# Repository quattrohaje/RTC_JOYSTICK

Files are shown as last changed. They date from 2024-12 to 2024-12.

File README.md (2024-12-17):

# RTC_JOYSTICK
There was one free ISA8bit slot left in my IBM5160, so I decided to build an RTC card. I also wanted to try drawing in the new one
the Kicad program and try exporting and ordering from the DPS manufacturer.

The whole project consists of two parts RTC and gamert. Why like this? Originally, I only wanted RTC, but I was afraid that the card wouldn't hold well in the ISA slot
so i added the gameport which is bolted to the milled blank.
As I already wrote, it can be divided into two parts
- "RTC" consists of components U1,U2,Y1,BT1,JP1,J1,R1,R2,R3
- "Gameport" then from U3,U4,U5,U7,C2,C3,C4,C5,C6,C7,C8,C9,C10,C11,R4,R5,R6,R7,RN1 and RN2
- "Common" Capacitor C1 is common to both connections and should always be fitted.
Component values are not critical
- 10k resistors are classic metallic
- the 10n capacitors are ceramic
- the 51p capacitors are ceramic, it is not important to observe the exact value here, they can be 30-100p with a large tolerance (but probably all the same)
- RN1 8x1k0 8xresistor with common one input, RN2 4x10k 4x resistor with common one input. For RN2 it is good to stick to the 10k value

JP1 is used to clear the RTC clock in the DS12885 circuit
J1 is used to set the address to which the RTC circuit will communicate. I recommend 0x240 i.e. A1 shorted using a jumper

The installation is not complicated, there is no trickery.

I compiled the programs for GAL using Wincurl

The driver for controlling the RTC circuit is written in ASM and translated using NASM. Driver usage is in config.sys
device=c:\ibm\dsclock.sys 0x240
The driver is not completely finished yet, there were some errors in the original, I corrected them, but I still have to fine-tune it. The driver works with both RTC and gameport

A few photos from the project
rtc1
rtc2
rtc4
rtc5
rtc6
rtc7

https://github.com/user-attachments/assets/15338810-2ce5-4af2-8db0-e2d07ca02ab5

The inspiration was in these projects on github
https://github.com/spark2k06/RTC8088
https://github.com/roybaer/game_control_adapter

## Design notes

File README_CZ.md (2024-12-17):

# RTC_JOYSTICK
RTC a Joystick interface pro ISA 8bit XT/AT PC

V mém IBM5160 zbyl ještě jeden volný ISA8bit slot a tak jsem se rozhodl, že si postavím kartu RTC. Chtěl jsem si také vyzkoušet kreslit v novém
programu Kicad a  vyzkoušet export a objednání u výrobce DPS.

Celý projekt se skládá ze dvou částí RTC a gamertu. Proč takto ? Původně jsem chtěl jen RTC, ale bál jsem se , že by karta špatně držela v ISA slotu
a tak jsem přidal gameport, který je přišroubován k frézované záslepce.
Jak jsem již psal, dá se to rozdělit na dvě části 
- "RTC" se skládá ze součástek U1,U2,Y1,BT1,JP1,J1,R1,R2,R3
- "Gameport" pak z U3,U4,U5,U7,C2,C3,C4,C5,C6,C7,C8,C9,C10,C11,R4,R5,R6,R7,RN1 a RN2
- "Společné" Kondenzátor C1 je společný pro obě zapojení a měl by být vždy osazen.
Hodnoty součástek nejsou kritické 
- odpory 10k jsou klasické metalické
- kondenzátory 10n jsou keramické
- kondenzátory 51p jsou keramické, zde není důležité dodržet přesnou hodnotu můžou být s velkou tolerancí 30-100p (ale asi všechny stejně)
- RN1 8x1k0 8xrezistor se společným jedním vstupem, RN2 4x10k 4x rezistor se společným jedním vstupem . U RN2 je dobré dodržet 10k hodnotu

JP1 slouží k výmazu RTC hodin v obvodu DS12885
J1 slouží k nastavení adresy na které bude komunikovat RTC obvod. Doporučuji 0x240 tj. A1 zkratovaný pomocí jumperu

Osazení není složité, není tam žádná záludnost.

Programy pro GAL jsem kompiloval pomocí Wincurl

Driver pro ovládání RTC obvodu je psán v ASM a přeložen pomocí NASM. Použití driveru je v config.sys
device=c:\ibm\dsclock.sys 0x240
Driver ještě není úplně hotov, v originál byly nějaké chyby, ty jsem upravil, ale ještě to musím doladit. Driver funguje jak s RTC tak gameportem 

Pár fotek z projektu
rtc1
rtc2
rtc4
rtc5
rtc6
rtc7

https://github.com/user-attachments/assets/15338810-2ce5-4af2-8db0-e2d07ca02ab5

Inspirace byla v těchto projektech na github
https://github.com/spark2k06/RTC8088
https://github.com/roybaer/game_control_adapter

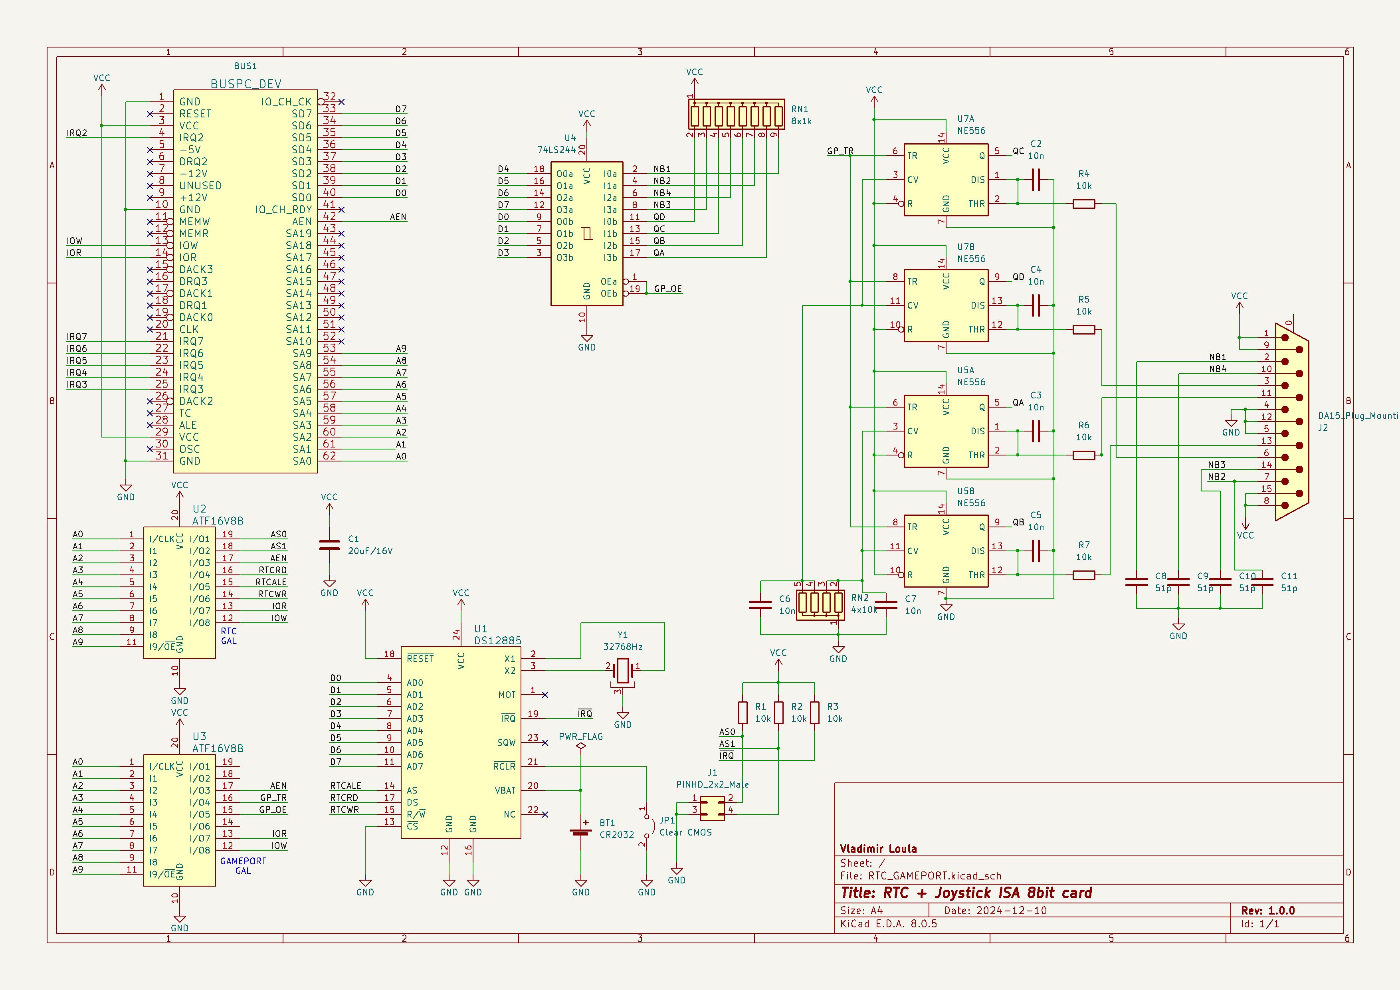
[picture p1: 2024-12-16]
Schematic.jpg

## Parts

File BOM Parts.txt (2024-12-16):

U1	DS12885		DIL24
U2	GAL16V8		DIL20
U3	GAL16V8		DIL20
U4	74LS244		DIL20
U5	NE556		DIL14
U7	NE556		DIL14
Y1	32768Hz
C1	20uF/16V
C2	10n
C3	10n
C4	10n
C5	10n
C6	10n
C7	10n
C8	50p
C9	50p
C10	50p
C11	50p
R1	10k
R2	10k
R3	10k
R4	10k
R5	10k
R6	10k
R7	10k
RN1	8x1k0
RN2	4x10k
J1 	2x2 pinhead
JP1	1x2 pinhead
J2	DSUB15 female 90° PCB
JMP1	jumper
JMP2	jumper
JMP3	jumper
BT1   držák na baterii CR2032

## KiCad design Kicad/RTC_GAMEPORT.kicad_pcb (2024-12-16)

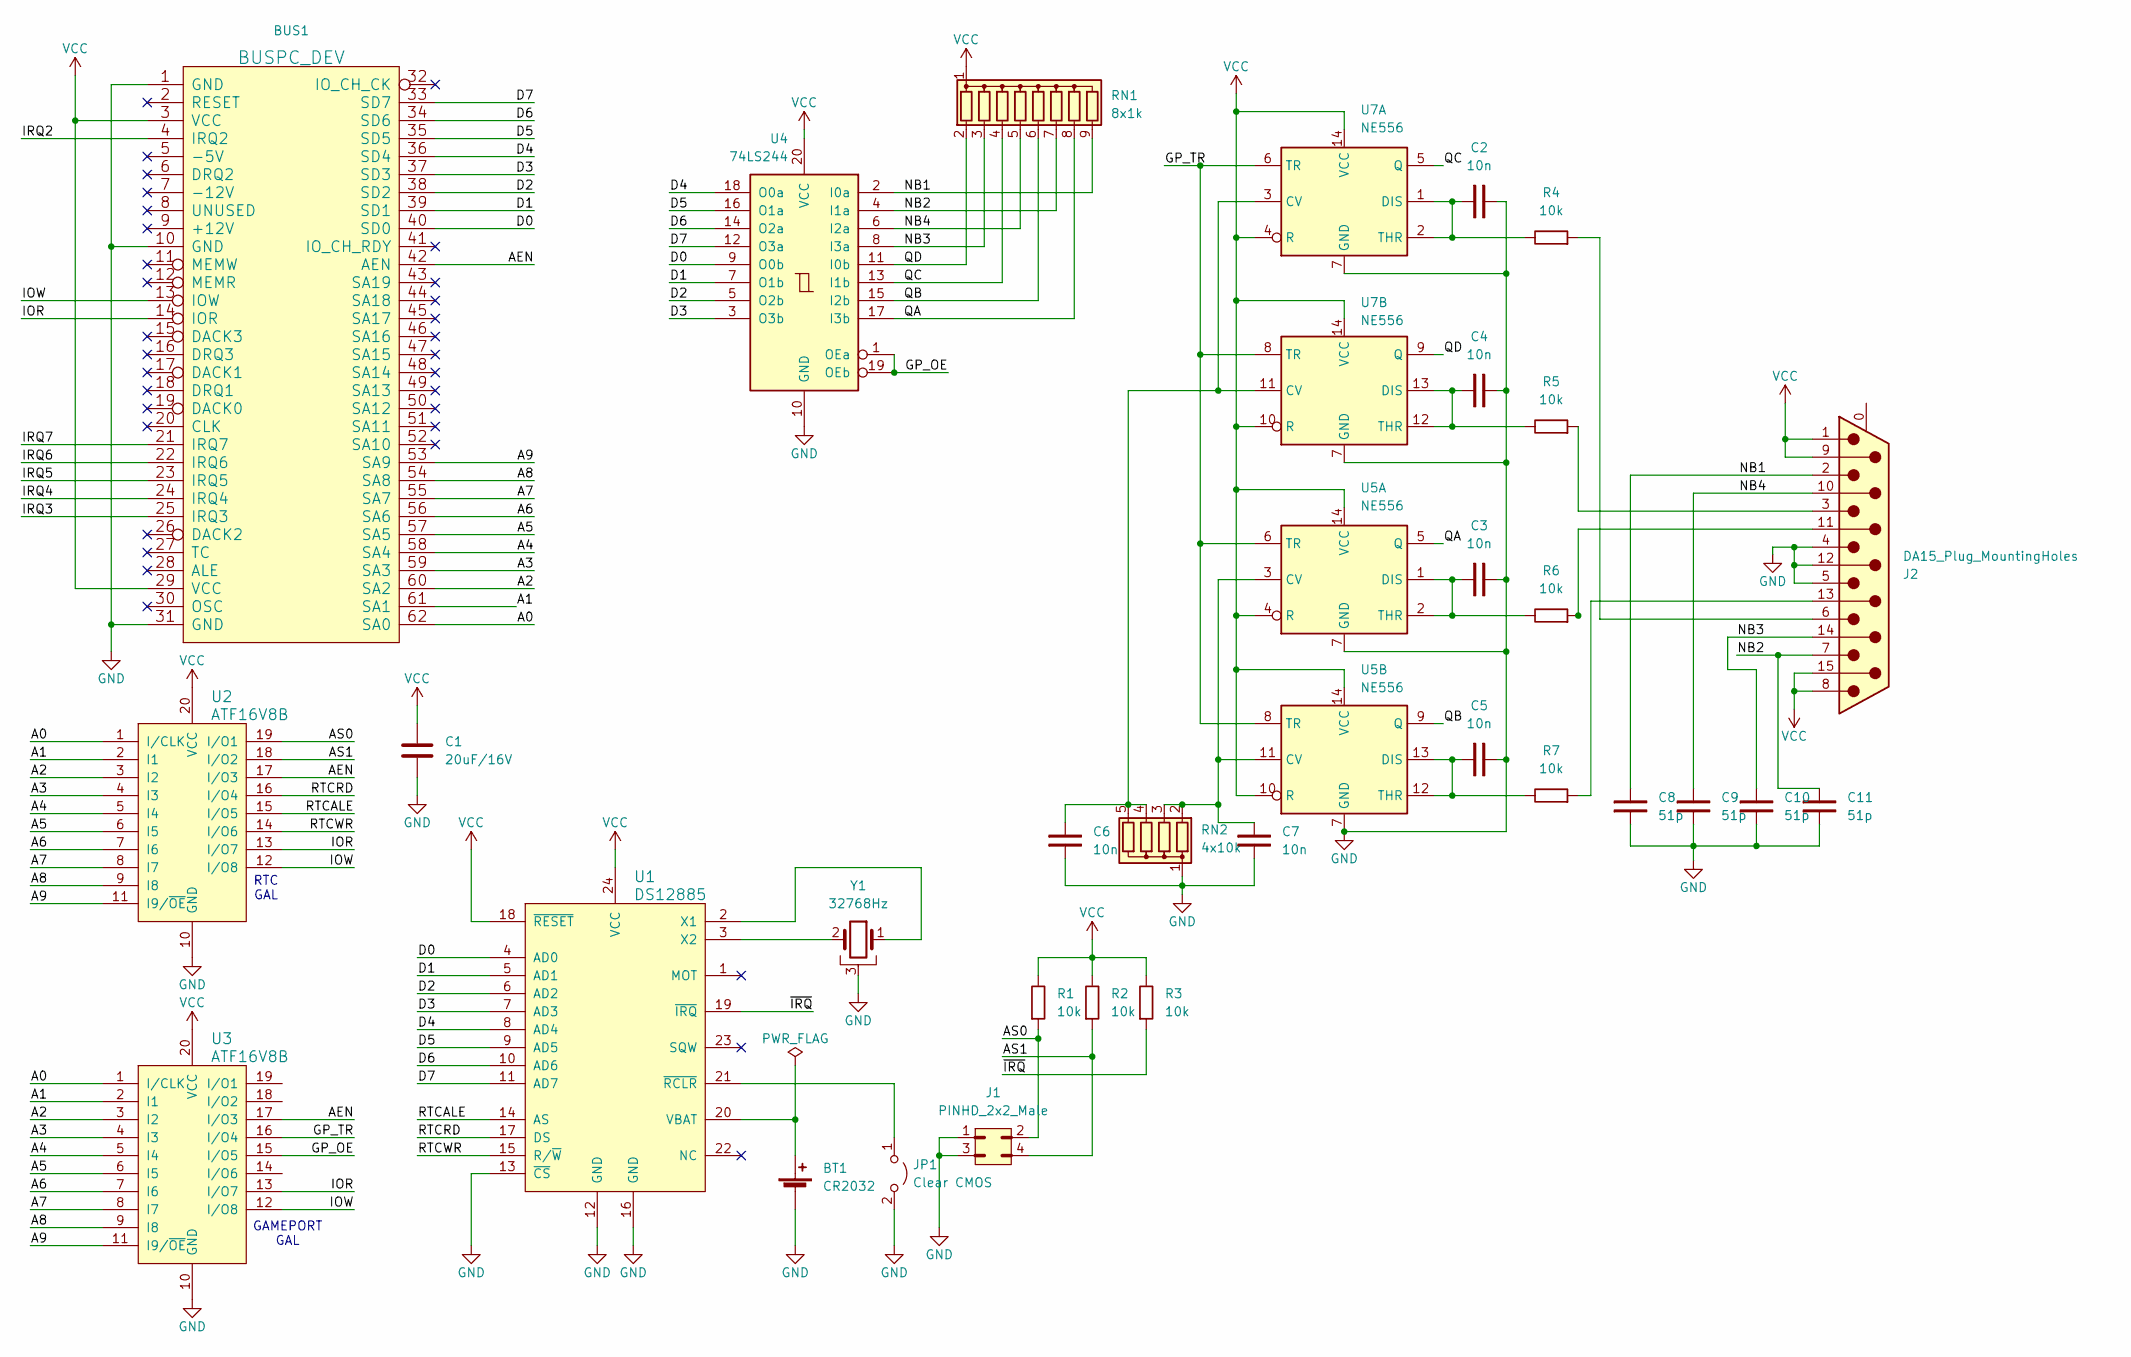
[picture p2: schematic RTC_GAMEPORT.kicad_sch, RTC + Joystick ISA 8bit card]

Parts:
BT1: CR2032; BatteryHolder_ComfortableElectronic_CH273-2450_1x2450
BUS1: BUSPC_DEV; Conn_Edge_PCB_ISA8
C1: 20uF/16V; CP_Radial_D8.0mm_P5.00mm
C2, C3, C4, C5, C6, C7: 10n; C_Rect_L7.0mm_W3.5mm_P5.00mm
C8, C9, C10, C11: 51p; C_Rect_L7.0mm_W3.5mm_P5.00mm
J1: PINHD_2x2_Male; PinHeader_2x02_P2.54mm_Vertical
J2: DA15_Plug_MountingHoles; DSUB-15_Female_Horizontal_P2.77x2.84mm_EdgePinOffset7.70mm_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
JP1: Clear CMOS; PinHeader_1x02_P2.54mm_Vertical
R1, R2, R3, R4, R5, R6, R7: 10k; R_Axial_DIN0207_L6.3mm_D2.5mm_P10.16mm_Horizontal
RN1: 8x1k; R_Array_SIP9
RN2: 4x10k; R_Array_SIP5
U1: DS12885; DIP-24_W15.24mm_Socket_LongPads
U2, U3: ATF16V8B; DIP-20_W7.62mm_Socket_LongPads
U4: 74LS244; DIP-20_W7.62mm
U5, U7: NE556; DIP-14_W7.62mm_LongPads
Y1: 32768Hz; Crystal_AT310_D3.0mm_L10.0mm_Horizontal_1EP_style2

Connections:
/A0: BUS1.62 (SA0), U2.1 (I/CLK), U3.1 (I/CLK)
/A1: BUS1.61 (SA1), U2.2 (I1), U3.2 (I1)
/A2: BUS1.60 (SA2), U2.3 (I2), U3.3 (I2)
/A3: BUS1.59 (SA3), U2.4 (I3), U3.4 (I3)
/A4: BUS1.58 (SA4), U2.5 (I4), U3.5 (I4)
/A5: BUS1.57 (SA5), U2.6 (I5), U3.6 (I5)
/A6: BUS1.56 (SA6), U2.7 (I6), U3.7 (I6)
/A7: BUS1.55 (SA7), U2.8 (I7), U3.8 (I7)
/A8: BUS1.54 (SA8), U2.9 (I8), U3.9 (I8)
/A9: BUS1.53 (SA9), U2.11 (I9/~OE), U3.11 (I9/~OE)
/AEN: BUS1.42 (AEN), U2.17 (I/O3), U3.17 (I/O3)
/AS0: J1.2, R1.1, U2.19 (I/O1)
/AS1: J1.4, R2.1, U2.18 (I/O2)
/D0: BUS1.40 (SD0), U1.4 (AD0), U4.9 (O0b)
/D1: BUS1.39 (SD1), U1.5 (AD1), U4.7 (O1b)
/D2: BUS1.38 (SD2), U1.6 (AD2), U4.5 (O2b)
/D3: BUS1.37 (SD3), U1.7 (AD3), U4.3 (O3b)
/D4: BUS1.36 (SD4), U1.8 (AD4), U4.18 (O0a)
/D5: BUS1.35 (SD5), U1.9 (AD5), U4.16 (O1a)
/D6: BUS1.34 (SD6), U1.10 (AD6), U4.14 (O2a)
/D7: BUS1.33 (SD7), U1.11 (AD7), U4.12 (O3a)
/GP_OE: U3.15 (I/O5), U4.1 (OEa), U4.19 (OEb)
/GP_TR: U3.16 (I/O4), U5.6 (TR), U5.8 (TR), U7.6 (TR), U7.8 (TR)
/IOR: BUS1.14 (IOR), U2.13 (I/O7), U3.13 (I/O7)
/IOW: BUS1.13 (IOW), U2.12 (I/O8), U3.12 (I/O8)
/IRQ2: BUS1.4 (IRQ2)
/IRQ3: BUS1.25 (IRQ3)
/IRQ4: BUS1.24 (IRQ4)
/IRQ5: BUS1.23 (IRQ5)
/IRQ6: BUS1.22 (IRQ6)
/IRQ7: BUS1.21 (IRQ7)
/NB1: C8.2, J2.2, RN1.9 (R8), U4.2 (I0a)
/NB2: C11.2, J2.7, RN1.7 (R6), U4.4 (I1a)
/NB3: C10.2, J2.14, RN1.3 (R2), U4.8 (I3a)
/NB4: C9.2, J2.10, RN1.5 (R4), U4.6 (I2a)
/QA: RN1.8 (R7), U4.17 (I3b), U5.5 (Q)
/QB: RN1.6 (R5), U4.15 (I2b), U5.9 (Q)
/QC: RN1.4 (R3), U4.13 (I1b), U7.5 (Q)
/QD: RN1.2 (R1), U4.11 (I0b), U7.9 (Q)
/RTCALE: U1.14 (AS), U2.15 (I/O5)
/RTCRD: U1.17 (DS), U2.16 (I/O4)
/RTCWR: U1.15 (R/~W), U2.14 (I/O6)
/~IRQ: R3.1, U1.19 (~IRQ)
GND: BT1.2 (-), BUS1.1 (GND), BUS1.10 (GND), BUS1.31 (GND), C1.2, C2.2, C3.2, C4.2, C5.2, C6.1, C7.1, C8.1, C9.1, C10.1, C11.1, J1.1, J1.3, J2.4, J2.5, J2.12, JP1.2 (B), RN2.1 (common), U1.12 (GND), U1.13 (~CS), U1.16 (GND), U2.10 (GND), U3.10 (GND), U4.10 (GND), U5.7 (GND), U7.7 (GND), Y1.3
unnamed: BT1.1 (+), U1.20 (VBAT)
unnamed: J2.13, R7.1
unnamed: J2.11 (P111), R6.1
unnamed: J2.3, R5.1
unnamed: J2.6, R4.1
unnamed: JP1.1 (A), U1.21 (~RCLR)
unnamed: C7.2, RN2.2 (R1), RN2.3 (R2), U5.3 (CV), U5.11 (CV)
unnamed: C6.2, RN2.4 (R3), RN2.5 (R4), U7.3 (CV), U7.11 (CV)
unnamed: U1.2 (X1), Y1.1
unnamed: U1.3 (X2), Y1.2
unnamed: C3.1, R6.2, U5.1 (DIS), U5.2 (THR)
unnamed: C5.1, R7.2, U5.12 (THR), U5.13 (DIS)
unnamed: C2.1, R4.2, U7.1 (DIS), U7.2 (THR)
unnamed: C4.1, R5.2, U7.12 (THR), U7.13 (DIS)
VCC: BUS1.3 (VCC), BUS1.29 (VCC), C1.1, J2.1, J2.8, J2.9, J2.15, R1.2, R2.2, R3.2, RN1.1 (common), U1.18 (~RESET), U1.24 (VCC), U2.20 (VCC), U3.20 (VCC), U4.20 (VCC), U5.4 (R), U5.10 (R), U5.14 (VCC), U7.4 (R), U7.10 (R), U7.14 (VCC)

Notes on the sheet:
GAMEPORT GAL
RTC GAL

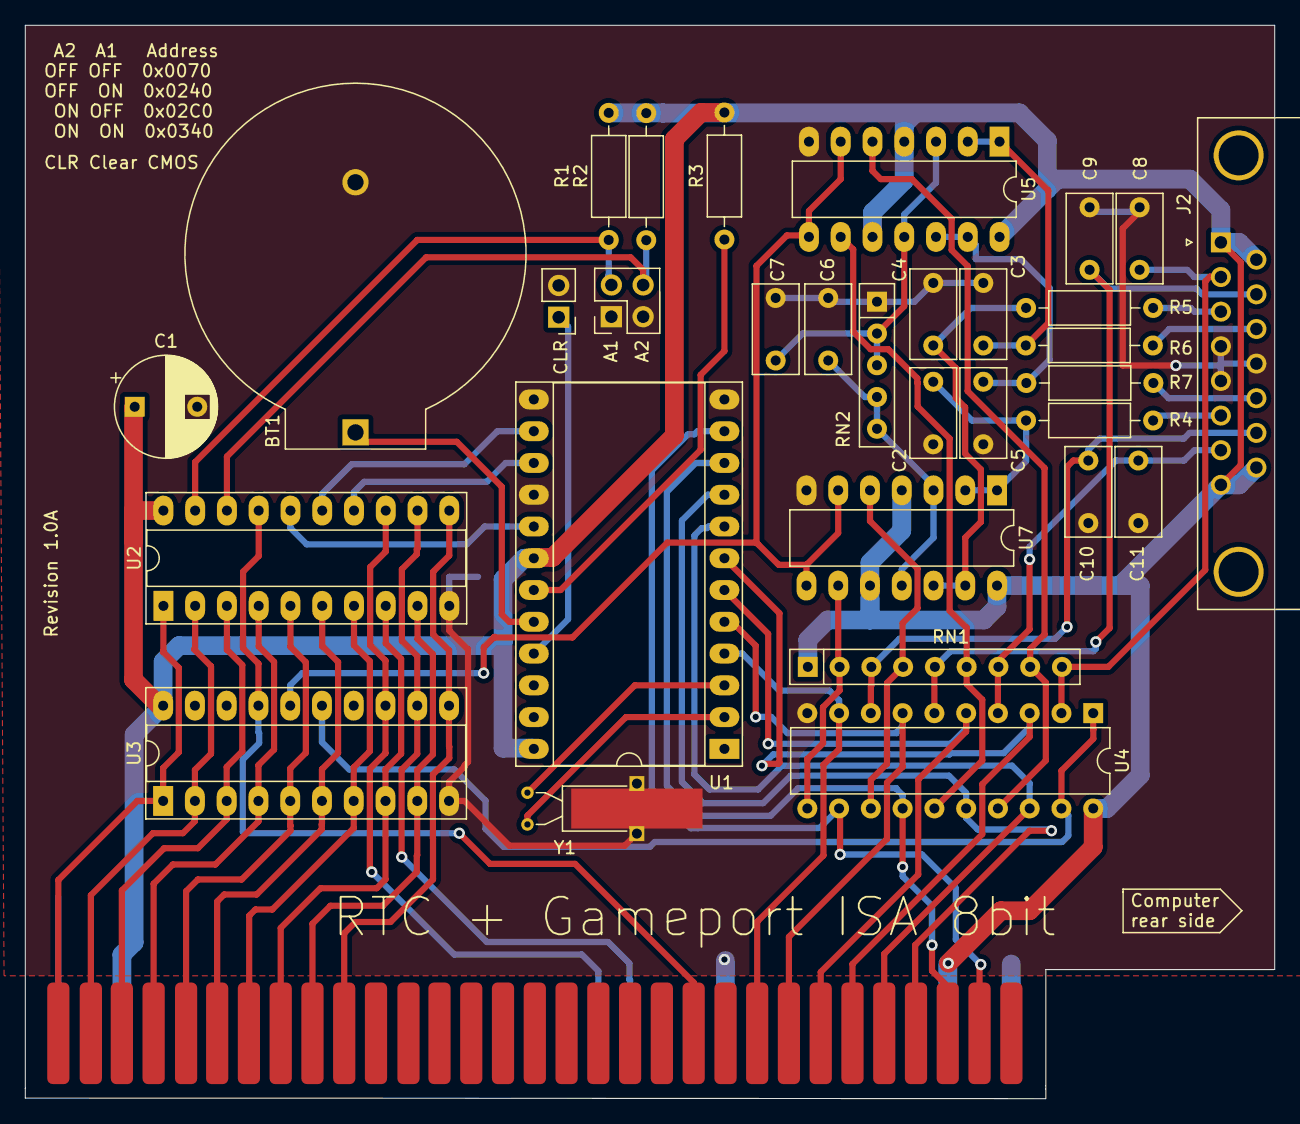
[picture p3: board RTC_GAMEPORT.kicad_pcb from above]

Board: 2 copper layers, 99.9 x 85.8 mm, 31 parts (0 on the bottom side), 53 nets.

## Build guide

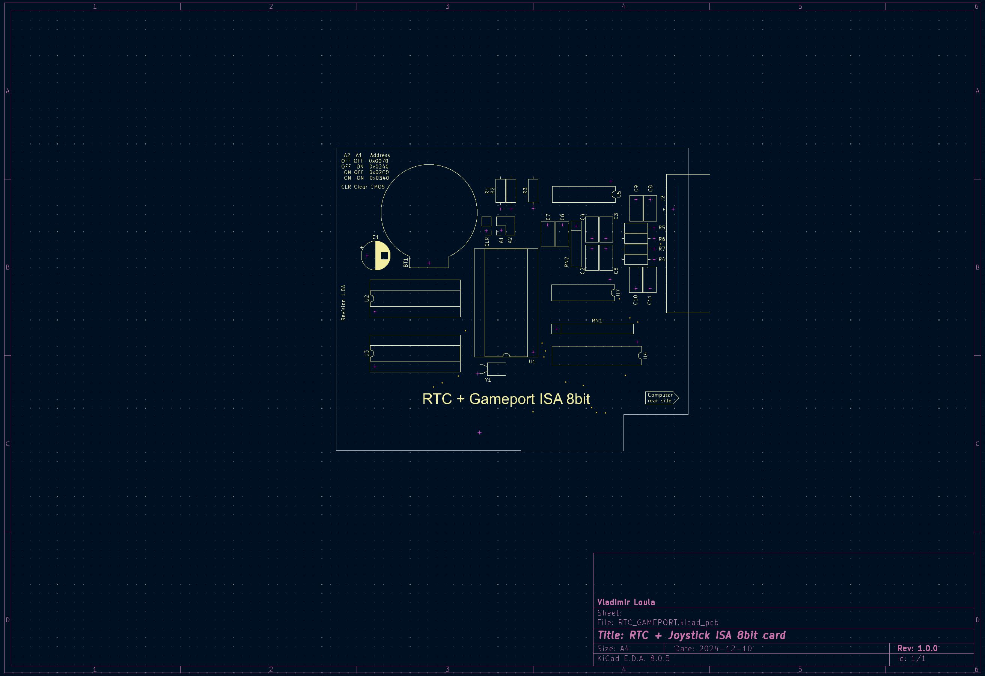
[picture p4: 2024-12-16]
PCB assembly.jpg

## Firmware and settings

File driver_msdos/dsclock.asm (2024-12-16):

;=========================================================================
; clock.asm - MS-DOS Clock driver 
;-------------------------------------------------------------------------
;
; Compiles with NASM 2.13.02, might work with other versions
;
; Copyright (C) 2024 - Sergey Kiselev.
; Provided for hobbyist use with the RTC8088 boards.
;
; This program is free software: you can redistribute it and/or modify
; it under the terms of the GNU General Public License as published by
; the Free Software Foundation, either version 3 of the License, or
; (at your option) any later version.
;
; This program is distributed in the hope that it will be useful,
; but WITHOUT ANY WARRANTY; without even the implied warranty of
; MERCHANTABILITY or FITNESS FOR A PARTICULAR PURPOSE.  See the
; GNU General Public License for more details.
;
; You should have received a copy of the GNU General Public License
; along with this program.  If not, see <http://www.gnu.org/licenses/>.
;
;=========================================================================

	cpu	8086

;-------------------------------------------------------------------------
; RTC default I/O port
default_io_port	equ	240h

;-------------------------------------------------------------------------
; locations in RTC and NVRAM
cmos_seconds	equ	00h	; seconds location in RTC
cmos_alarm_secs	equ	01h	; alarm seconds location in RTC
cmos_minutes	equ	02h	; minutes location in RTC
cmos_alarm_mins	equ	03h	; alarm minutes location in RTC
cmos_hours	equ	04h	; hours locaiton in RTC
cmos_alarm_hrs	equ	05h	; alarm hours location in RTC
cmos_day	equ	06h	; day location in RTC
cmos_date	equ	07h	; date location in RTC
cmos_month	equ	08h	; month location in RTC
cmos_year	equ	09h	; year location in RTC
cmos_floppy	equ	10h	; floppy type byte
cmos_equip	equ	14h	; equipment byte
cmos_config_a	equ	2Dh	; BIOS configuration byte A
cmos_sum_hi	equ	2Eh	; checksum of bytes 10h - 20h - high byte
cmos_sum_lo	equ	2Fh	; checksum of bytes 10h - 20h - low byte 
cmos_century	equ	32h	; centry location in RTC (DS12C887 only)

;-------------------------------------------------------------------------
; RTC control register and their bits
cmos_control_a	equ	0Ah	; RTC control A register
cmos_uip	equ	80h	; RTC update in progress bit
cmos_control_b	equ	0Bh	; RTC control B register
cmos_dse	equ	01h	; RTC daylight savings enable bit
cmos_24hours	equ	02h	; RTC 24 hours format (1 = 24 hours, 0 = 12)
cmos_uie	equ	10h	; RTC update ended interrupt enable bit
cmos_aie	equ	20h	; RTC alarm interrupt enable bit
cmos_pie	equ	40h	; RTC periodic interrupt enable bit
cmos_set	equ	80h	; RTC set bit (0 = normal operation, 1 = set)
cmos_control_c	equ	0Ch	; RTC control C register
cmos_uf		equ	20h	; RTC update ended interrupt flag
cmos_af		equ	40h	; RTC alarm interrupt flag
cmos_pf		equ	80h	; RTC periodic interrupt flag
cmos_control_d	equ	0Dh	; RTC control D register
cmos_vrt	equ	80h	; RTC vrt bit (1 = battery is OK)

;-------------------------------------------------------------------------
; Device driver - Request header - common fields (13 bytes)
cmdlen		equ	0	; Length of this command (1 byte)
unit		equ	1	; Subunit Specified (1 byte)
cmd		equ	2	; Command Code (1 byte)
status		equ	3	; Status (2 bytes / 1 word)
reserved	equ 	5	; Reserved (8 bytes)
; Device driver - Request header - Init function
num_units	equ	13	; Number of units (1 byte)
end_addr	equ	14	; End address of the driver (dword/4 bytes)
cmd_addr	equ	18	; Pointer to command line arguments + CR/LF
; Device driver - Request header - Read/Write functions
transfer_addr	equ	14	; Transfer address (dword/4 bytes)

;-------------------------------------------------------------------------
; Device driver - Commands and status
cmd_init	equ	0h	; "Init" command
cmd_read	equ	4h	; "Read" command
cmd_write	equ	8h	; "Write" command
status_done	equ	0100h	; "Done" status, bit 8 set
status_fail	equ	800Ch	; "Error" - bit 15 set + "General Failure" - 0Ch

;-------------------------------------------------------------------------
; MS-DOS reads or writes the following 6-byte sequence to clock device:
clk_days	equ	0h	; days since 01/01/1980 - word
clk_minutes	equ	2h	; minutes - byte
clk_hours	equ	3h	; hours - byte
clk_cseconds	equ	4h	; centiseconds - byte
clk_seconds	equ	5h	; seconds - byte 
;=========================================================================
; Colors for text
;-------------------------------------------------------------------------
color_black      	equ 00h  ; Black
color_blue       	equ 01h  ; Blue
color_green      	equ 02h  ; Green
color_cyan       	equ 03h  ; Cyan
color_red        	equ 04h  ; Red
color_magenta    	equ 05h  ; Magenta
color_brown      	equ 06h  ; Brown
color_light_gray 	equ 07h  ; Light Gray
color_dark_gray  	equ 08h  ; Dark Gray
color_light_blue 	equ 09h  ; Light Blue
color_light_green 	equ 0Ah ; Light Green
color_light_cyan 	equ 0Bh  ; Light Cyan
color_light_red  	equ 0Ch  ; Light Red
color_light_magenta 	equ 0Dh ; Light Magenta
color_yellow     	equ 0Eh  ; Yellow
color_white      	equ 0Fh  ; White

	org	0h		; device drivers start at the offset 0h

;=========================================================================
; Device driver header
;-------------------------------------------------------------------------
device_header	dw	0FFFFh, 0FFFFh	; next device pointer - last device
		dw	1000000000001000b ; driver attributes
;			|           `--- clock device
;			`--------------- character device
		dw	strategy	; strategy entry point
		dw	entry		; device driver entry point
		db	'CLOCK$  '	; device name

;=========================================================================
; Clock driver data
;-------------------------------------------------------------------------
request_ptr	dd	0		; pointer to the request header
rtc_io_port	dw	0240h		; use I/O port 240h by default
seconds		db	cmos_seconds,0	; last seconds value read or written
minutes		db	cmos_minutes,0	; last minutes value read or written
hours		db	cmos_hours,0	; last hours value read or written
day		db	cmos_day,0	; last day value read or written
date		db	cmos_date,0	; last date value read or written
month		db	cmos_month,0	; last month value read or written
year		db	cmos_year,0	; last year value read or written
century		db	cmos_century,0	; last century value read or written
num_rtc_regs	equ	($-seconds)/2	; number of RTC registers
ticks		dw	0		; initial ticks value for read time
days_in_month	db	31, 28, 31, 30, 31, 30, 31, 31, 30, 31, 30, 31
;=========================================================================
; strategy - MS-DOS calls this function first, passing the request header
;            address. This function stores that address in request_ptr
; Input:
;	ES:BX = request header address
; Output:
;	none
;-------------------------------------------------------------------------
strategy:
	mov	cs:[request_ptr],bx	; save request header address
	mov	cs:[request_ptr+2],es
	retf
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
